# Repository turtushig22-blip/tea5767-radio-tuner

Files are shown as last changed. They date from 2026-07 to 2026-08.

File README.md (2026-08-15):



# TEA5767-based Radio Tuner
ESP32-based FM radio with TEA5767 tuner, KY-040 rotary encoder, PAM8403 amplifier, and 0.96" OLED display. Custom PCB design.

### Project History

The project built an FM radio device using the TEA5767 radio module and the Arduino UNO in January 2026. Phase 2 includes designing a compact, custom-designed PCB board with further improvements while keeping the design simple and reproducible. The steps will be documented in this repository as I work on the PCB design (so, hopefully, I can finish this project).

The primary functions of the prototype Arduino circuit include manual and preset FM tuning, displaying the current frequency on a 16x2 LCD, and outputting audio via wired headphones. We could not use speakers to output sound as the TEA5767 module does not have a built-in speaker amplifier, which required us to solder directly onto the module. Photos of the prototype circuit and the circuit diagrams are shown in Figures 1 and 2. 

   
<br>
Figure 1 [Photo of the prototype that used Arduino UNO].<br>

   
<br>
Figure 2 [Circuit Diagram of the prototype].<br>
<br>
To see a video demonstration of the prototype, please follow https://youtu.be/HQ7OcgIyThs, and for a detailed breakdown of the theory, component selection, and circuit design, you can read this [PDF File](Producing_an_FM_Radio_Tuner.pdf).<br>

## Evolving into a PCB design project
### Schematic 
To further improve the project, I decided to let it be my first PCB design while improving the radio device as well. The improvements that have been made include PAM8403 amplifier that will feed the audio into two 3-Watt, 4-Ohm speakers while working as a volume control, an ESP32 Development Board instead of the Arduino UNO to save space on the PCB, a 0.96 OLED display replacing the 16x2 Liquid Crystal Display for a similar reason, and a KY-040 rotary encoder that will serve as both the manual frequency and preset frequency control. 

Before diving into the PCB design, I took my time to make sure that the circuit works on a breadboard. During this process, I realized some important things which include how although the TEA5767 module is designed to be powered by 5V, it can be (and should) be powered by 3.3V to protect the data pins on the ESP32 module. The manufacturer of the microcontroller Nulllab mentioned that a voltage larger than 3.6V on the I/O pins can cause chip damage, and powering the TEA5767 module from 5V and connecting the SCL and SDA pins to the data pins on the microcontroller will drive them up to 5V, exposing them to the risk of being burnt out. More information about the ESP32-DevKit-32E can be found at [esp32-devkit-32e] (https://github.com/nulllaborg/esp32-devkit-32e).

Furthermore, what has caught attention includes how the PAM8403 needs to be powered by a source other than the microcontroller. The speakers I used are 3-Watt speakers (6-Watts in total since I have two speakers), so assuming that we power the amplifier with 5V, the amount of current we get is I = P / V = 6W / 5V = 1.2A. This amount of current through the microcontroller pins exceeds the manufacturer's specified limit (absolute MAX per pin: 40mA) by a huge amount. Therefore, the amplifier and the microcontroller are wired in parallel to a single transformer of 5V 1.5A capacity. As the amplifier required large current to operate and even larger current to blast music, it is recommended to use adapters that can supply more than 1A to avoid brownouts in other regions of the circuit when the volume is turned up.

Having that in mind, I started drawing the circuit diagram in KiCad's schematic editor. The schematic can be seen in Figure 3. 
 
<br>
Figure 3 [Schematic of the ESP32-based Circuit]. 
<br>

(To feed the audio signal from the TEA5767 module to the PAM8403 amplifier, I used a 3.5mm jack with a bare wire end, which was then connected to the L, G, and B pins on the amplifier. Note that these connections are not reflected in the schematic of the circuit as KiCad does not allow the schematic symbol of a device to have more pins than the device's footprint, which becomes a bit complicated for the TEA5767 module as it does not have designated pins for the L, G, R. One way to solve this is to draw the 3.5mm jack in the schematic editor; however, as the jack and the connection between the two modules will never actually touch the PCB, I decided to simply leave the pins on the amplifier not connected and draw the TEA5767 with only its physical pins).

### Footprints.
As the project required modules whose footprints do not readily exist in KiCad, I used it to learn to create custom footprints as well. The footprints for the ESP32-DevKit-32E, TEA5767, PAM8403, KY-040, and the 0.96 OLED Display are included in the `Custom_Footprints.pretty` folder. Photos of the custom footprints are attached below. 

    Figure 4 [ESP32-DevKit-32E Footprint].

    Figure 5 [TEA5767 footprint].

    Figure 6 [PAM8403 footprint].
<br>
(Note that the PAM8403 used in this project is the "knobby" version of the PAM8403 amplifier board, which allows it to work as the volume control. Furthermore, note that the knobs on the PAM8403 and KY-040 modules are not included in their corresponding footprints for the ease of drawing the footprint and because the boards will not physically touch the PCB).

     Figure 7 [KY-040 footprint].

    Figure 8 [0.96 OLED Display footprint].

### PCB Layout
After creating the custom footprints, I created the PCB design inside KiCad's PCB editor. A picture of the PCB layout from KiCad's PCB editor is shown in Figure 9. 


<br>
Figure 9 [PCB Layout of the Radio Module]. <br>
<br>
For this PCB project, I chose JLC PCB as the manufacturer. When making PCB orders, being aware of the manufacturer's capabilities is just as important as not shorting your circuit. Therefore, I paid close attention to whether the settings when generating the gerber files matched JLC's requirements, which can be seen from https://jlcpcb.com/capabilities/pcb-capabilities. 

The final Gerber files sent to the manufacturer can be found in the `gerbers` folder. Note that the silkscreen text reading *“The first of many. Grateful for everyone who supported me.”* has been removed from the manufacturing files, as it is personal and unnecessary for reproducing the board.

To see the code I used for this project, see the file named `code`.

The image of the PCB can be seen in Figures 10 and 11. 
 <br>
Figure 10 [The Front face of the PCB]. <br>

 <br>
Figure 11 [The Backside of the PCB]. <br>

The image of the device itself can be seen in Figure 12. 
 <br>
Figure 12 [An image of the ESP32-based Radio Module using TEA5767].<br>
<br>
To see a video demonstration of the PCB and the radio device, please follow https://www.youtube.com/watch?v=WM1Qq82G7yY.

Lastly, designing my first PCB has been a valuable learning experience and has strengthened my interest in electronics and hardware design. I hope this repository is useful to anyone building a similar project or beginning their own PCB design journey. I would like to thank the HTM Workshop team for their informative YouTube tutorial series, as well as my family and my girlfriend, Amy, for their encouragement and support throughout this project. <br>

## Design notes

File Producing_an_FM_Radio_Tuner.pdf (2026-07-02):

# Producing an FM Radio Tuner

Turtushig Dashjav and Meba Habte

January 29, 2026

Abstract

Capitalizing on the TEA5767 FM Stereo Radio module’s ability to pick up frequency signals and its built-in headphone amplifier, we created an Arduino circuit that tunes into FM radio channels and plays the audio through a headphone. We have two modes of input: PRESET, which allows the user to move between six known channel frequencies, and POT, which uses a potentiometer to vary the frequency. The LCD was used to make the circuit friendlier for the user by displaying what frequency one’s on and the mode they’re using.

## 1 Introduction

Electromagnetic waves are oscillations of magnetic and electric fields propagating through space at the speed of light. These waves, unlike mechanical waves, don’t require a medium to propagate. To characterize an electromagnetic wave, the following relationship between its frequency and wavelength with the speed of light is used: c = fλ.
Information is transferable through modulation—encoding of information onto a wave through the variation of either its amplitude or frequency [1]. FM (Frequency Modulation) encodes audio information into electromagnetic waves. When a radio receives this changed signal, it extracts information from the wave to determine the message that was sent. This also requires the radio to selectively respond to one frequency while ignoring others.
This project implements the Arduino UNO and a TEA5767 radio module to detect and demodulate these electromagnetic waves, allowing the user to listen to the audio output. (To see the code, consult the Appendix: Code).

## 2 Components

Table 1: Component List for Arduino FM Radio
Component | Qty | Purpose
Arduino UNO | 1 | Microcontroller board to control the radio
TEA5767 Module | 1 | Tunable FM Radio Chip
16x2 LCD Display | 1 | Displays current input mode and frequency
Potentiometer | 1 | Analog input for manual frequency tuning
Resistor 1kΩ | 1 | Prevents LCD from drawing excessive cur-rent
Resistor 220Ω | 1 | Prevents LCD from drawing excessive cur-rent
Pushbutton | 2 | Mode change and Preset step control
9V Battery | 1 | Supplies the Arduino and the circuit

The component list is based on [2]. (Note that we used headphones for the audio output instead of a speaker amplifier).

## 3 Circuit Description

At the heart of our circuit lies the Arduino. The Arduino receives information from the human-input components (the pushbuttons and the potentiometer) to specify a frequency or mode, and commands other components (LCD, TEA5767) to display input values and tune into FM channels.
POT mode: The potentiometer is a device that gives a variable resistance. The outer pins of the potentiometer are connected to the 5V rail and the ground rail. This allows the potentiometer to output a variable voltage (0-5V), which is then read by the Arduino to map it into the FM frequency band. This process is made possible by the Analogto-Digital Converter inside the Arduino, which determines the voltage change (analog) and translates it into frequency increments (digital). Then, the radio module tunes into that frequency, demodulates the signal, and produces it as audio through the headphones. The last component of the circuit, the LCD, is simply used as a tool to display the current mode and frequency.
PRESET mode: When the radio is turned on, the device is in the aforementioned POT mode. However, if the user pushes the mode button, the software reads that as LOW, causing the device to operate in the PRESET mode. In the PRESET mode, the second button is used to tune into one of six preset FM channels (88.1, 92.5, 94.5, 96.5, 102.3, 107.5 MHz). The circuit diagram and a photo of the device can be seen from Figures 1 and 2.

## 4 Conclusion and Future Improvements

This project demonstrates the use of modular design, state machines, and I²C communication to control hardware reliably. Though our radio device works and the audio quality is decent, it has limitations as well. It currently has no way to adjust the volume of the audio output. Furthermore, it is unable to output audio through speakers, as the TEA5767 module does not have a built-in speaker amplifier. Additional improvements to this project include adding a dual-gang potentiometer as the volume adjustment knob, which would require soldering it to the module itself. Adding a feature to switch between headphones and external speakers is another improvement.
Ultimately, this project allowed us to both exercise and expand our conceptual understanding of electronics to practical circuitry. Throughout its development, we faced many challenges due to the greater involvement we had in its design. This allowed us to develop an affinity for problem-solving and troubleshooting, which is the main objective of this course.

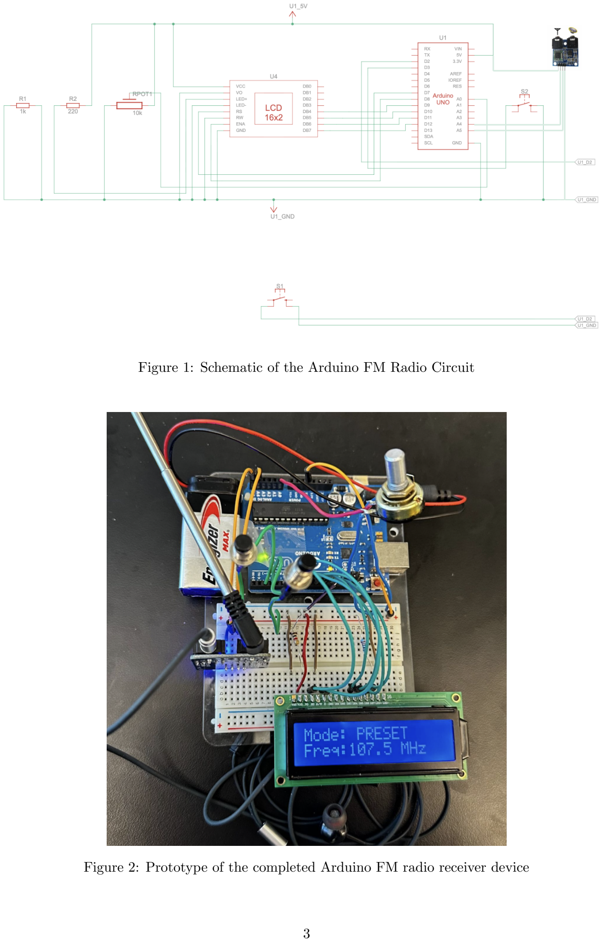
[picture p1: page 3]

Figure 1: Schematic of the Arduino FM Radio Circuit

Figure 2: Prototype of the completed Arduino FM radio receiver device

## References

[1] USC | Illumin, | “Catch | a | Wave: | Radio | Waves | and | How | They | Work.”
https://illumin.usc.edu/catch-a-wave-radio-waves-and-how-they-work/, | note = Accessed:
2026.
[2] YouTube, | “TEA5767 | FM | Radio | Module | for | your | Arduino | (Cheap!).”
https://www.youtube.com/watch?v=yWf9uxL6zgE, note = Accessed: 2026.
[3] V. Ceccoli, “Radio Arduino Uno TEA5767.” https://projecthub.arduino.cc/valerioceccoli/radio-arduino-uno-tea5767-0a4432. (https://projecthub.arduino.cc/valerioceccoli/radio-arduino-uno-tea5767-0a4432) Arduino Project Hub, Accessed: 2026.

## Appendix: Arduino Source Code

The following firmware implementation runs on the Arduino UNO microcontroller to manage frequency scaling, user inputs, and LCD interfacing.The codebase was adopted from Ceccoli [3], though a headphone was utilized in place of a speaker for the audio output.

1 | #include <Wire.h>
2 | #include <TEA5767.h>
3 | #include <LiquidCrystal.h>

4
5 TEA5767 radio;

6
7 | // LCD pins: RS, E, D4, D5, D6, D7
8 | LiquidCrystal lcd(7, 8, 9, 10, 11, 12);

9
10 | // PINS
11 | const int potPin | = A0;
12 | const int modeButtonPin = 2; // toggle pot / preset mode
13 | const int stepButtonPin = 3; // step through presets

14
15 | // STATE
16 | bool potMode = true; | // true = potentiometer mode
17 | bool lastModeButtonState = HIGH;
18 | bool lastStepButtonState = HIGH;

19
20 | // FREQUENCY DATA
21 | float currentFreq = 99.9;

22
23 | // Preset stations (MHz)
24 | float presets[] = { 88.1, 90.1, 92.5, 94.5, 96.5, 99.1, 102.3, 107.5 };
25 | const int presetCount = sizeof(presets) / sizeof(presets[0]);
26 | int presetIndex = 0;

27
28 | // LCD UPDATE
29 | void updateLCD(float freq) {
30 | lcd.setCursor(0, 0);
31 | if (potMode) {
32 | lcd.print("Mode: POT | ");
33 | } else {
34 | lcd.print("Mode: PRESET ");
35 | }

36
37 | lcd.setCursor(0, 1);
38 | lcd.print("Freq:");
39 | lcd.print(freq, 1);
40 | lcd.print(" MHz ");
41 | }

42
43 | void setup() {
44 | Wire.begin();
45 | Serial.begin(9600);

46
47 | pinMode(modeButtonPin, INPUT_PULLUP);
48 | pinMode(stepButtonPin, INPUT_PULLUP);

49
50 | lcd.begin(16, 2);
51 | lcd.clear();

52
53 radio.setFrequency(currentFreq);

54 updateLCD(currentFreq);

55
56 | Serial.println("FM Receiver Started");
57 | }

58
59 | void loop() {
60 | // MODE TOGGLE BUTTON
61 | bool modeButtonState = digitalRead(modeButtonPin);

62
63 | if (lastModeButtonState == HIGH && modeButtonState == LOW) {
64 | potMode = !potMode;
65 | updateLCD(currentFreq);
66 | }
67 | lastModeButtonState = modeButtonState;

68
69 | // POTENTIOMETER MODE
70 | if (potMode) {
71 | int potValue = analogRead(potPin);

72
73 | // Using potValue to calculate new frequency
74 | float newFreq = 87.5 + (potValue / 1023.0) * (108.0 - 87.5);
75 | newFreq = round(newFreq * 10.0) / 10.0;

76
77 | if (abs(newFreq - currentFreq) >= 0.1) {
78 | currentFreq = newFreq;
79 | radio.setFrequency(currentFreq);
80 | updateLCD(currentFreq);

81
82 | Serial.print("POT tune: ");
83 | Serial.println(currentFreq);
84 | }
85 | }

86
87 | // PRESET MODE
88 | else {
89 | bool stepButtonState = digitalRead(stepButtonPin);

90
91 | if (lastStepButtonState == HIGH && stepButtonState == LOW) {
92 | presetIndex++;

93
94 | if (presetIndex >= presetCount) {
95 | presetIndex = 0; // wrap around
96 | }

97
98 | currentFreq = presets[presetIndex];
99 | radio.setFrequency(currentFreq);
100 | updateLCD(currentFreq);

101
102 | Serial.print("PRESET tune: ");
103 | Serial.println(currentFreq);
104 | }
105 | lastStepButtonState = stepButtonState;
106 | }
107 | }

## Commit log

2026-06-26 Revise README for project evolution and new features
    Updated the README to reflect the project's evolution from a prototype to a PCB design, including new features and components.
2026-06-29 Replace schematic image in README
    Updated the image in the README to reflect the latest schematic.
2026-07-02 Revise README for Arduino Radio Module project
    Updated project description for clarity and detail.
2026-07-03 Revert "Pcb design"
2026-07-03 Revise README with project updates and PCB design info
    Updated project description and added PCB design section with details on improvements and schematic.
2026-07-03 Update README with custom footprints details
    Added section on custom footprints with images.
2026-07-03 Revise schematic and footprint descriptions in README
    Updated the README to enhance clarity and formatting.
2026-07-03 Add images and details for PCB design improvements
    Updated the README.md to include images of custom footprints and schematic.
2026-07-03 Update README with new figures and component details
    Added additional figures and descriptions for PCB components, including footprints for PAM8403, KY-040, and 0.96 OLED Display.
2026-07-03 Revise README for clarity and project updates
    Updated project title and improved clarity in the README. Added details about the PCB design process and custom footprints.
2026-07-08 Add housing design section to README
    Added a section on housing design for the PCB project, detailing the use of vinyl downspout pipes and providing guidance on alternatives.
2026-07-28 Create gerber files
2026-08-03 Create gerbers
2026-08-03 cleaned up duplicate gerber files
    [ESP32_Radio_Module-B_Mask.gbs, ESP32_Radio_Module-B_Paste.gbp, ESP32_Radio_Module-B_Silkscreen.gbo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]
2026-08-04 Update README with images and remove duplicates
    Removed duplicate figure captions and added new images for the PCB layout and device.
2026-10-29 Enhance README with enclosure design and thanks
    Added details about the 3D printed enclosure design and acknowledgments.

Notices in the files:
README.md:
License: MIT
